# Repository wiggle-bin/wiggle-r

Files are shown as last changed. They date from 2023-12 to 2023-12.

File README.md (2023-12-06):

# WiggleR

The mission of **WiggleBin** is to craft an **open-source, intelligent [vermicomposting](https://en.wikipedia.org/wiki/Vermicompost) bin** that cultivates joy for both earthworms and their human stewards. 

In order to craft an open-source, intelligent composting bin, we want to understand the [Umwelt](https://en.wikipedia.org/wiki/Umwelt) (perceptual world) of worms. Hence, we've introduced the [WiggleR](./BUILD.md), our innovative open-source desktop composting research unit.

Join us in this thrilling endeavor! Embark on a captivating, modern-day Darwinian journey into the realm of worms by creating your very own [WiggleR](./BUILD.md).

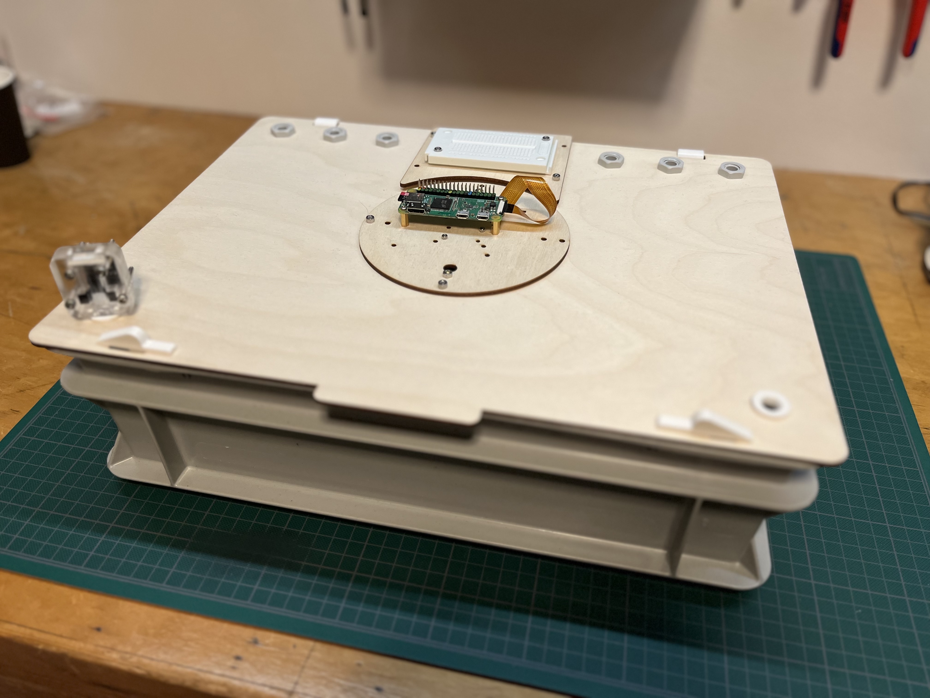
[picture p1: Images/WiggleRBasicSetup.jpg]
WiggleR - innovative open-source desktop composting research unit


## Why?

Delving into the essence of worm happiness raises intriguing queries: What defines a worm's contentment? How can we gauge their emotional state? Moreover, how do these fascinating creatures navigate and perceive their surroundings through their unique sensory mechanisms?

Unraveling these enigmas not only enhances our understanding of these small but vital ecosystem contributors but also deepens our appreciation for the interconnectedness of life on a microcosmic level.

## License

The WiggleBin is open source hardware. Hardware is covered under CERN-OHL-S-2.0 (`LICENSE.CERN-OHL-S-2.0.txt`) license and software under GPL-3.0-or-later (`LICENSE.GPL-3.0-or-later.txt`) license.

## Status

This project is in the research and testing phase. Currently our research involves trying out different sensors. See [issues](https://github.com/studiorabota/wiggle-bin/issues) for more info and how to contribute. Check [milestones](https://github.com/studiorabota/wiggle-bin/milestones) for our future plans.

## Thanks!

Many thanks to [Open Hardware Academy](https://www.openhardware.academy/01_Welcome.html) and [Stadslab Rotterdam](https://stadslabrotterdam.nl/) for making this project possible.

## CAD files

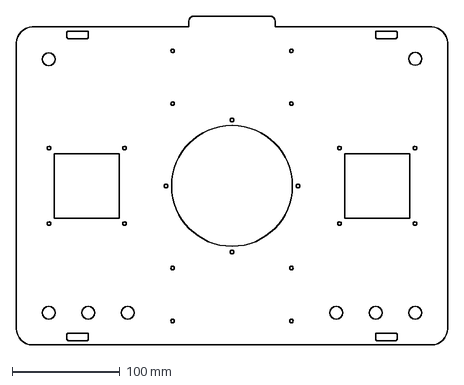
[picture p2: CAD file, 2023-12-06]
Design/BinTop/MainPlate.dxf
400.0 x 305.0 mm

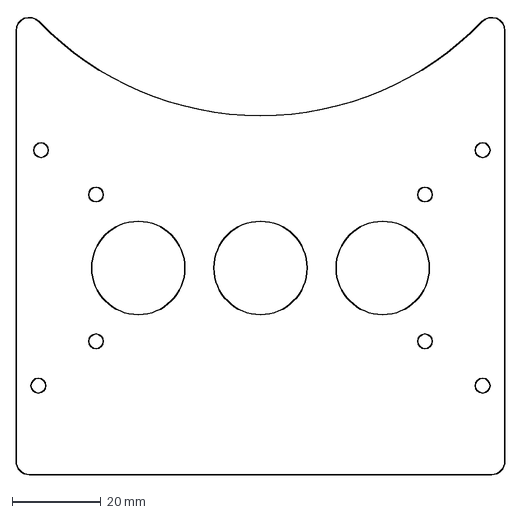
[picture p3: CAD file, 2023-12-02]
Design/BinTop/BreadboardUnit/BreadBoardPlate.dxf
110.0 x 103.1 mm

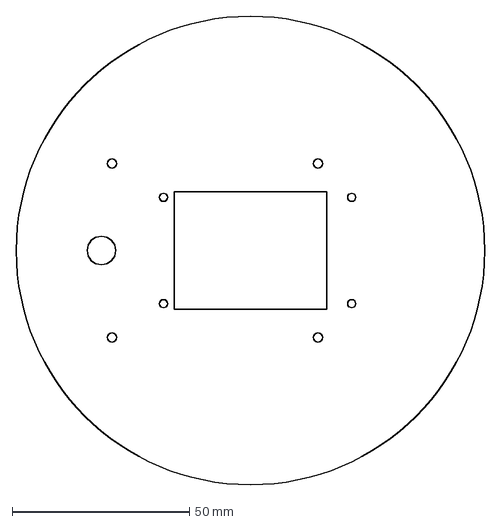
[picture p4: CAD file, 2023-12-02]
Design/BinTop/CenterUnit/DisplayBracket.dxf
132.0 x 132.0 mm

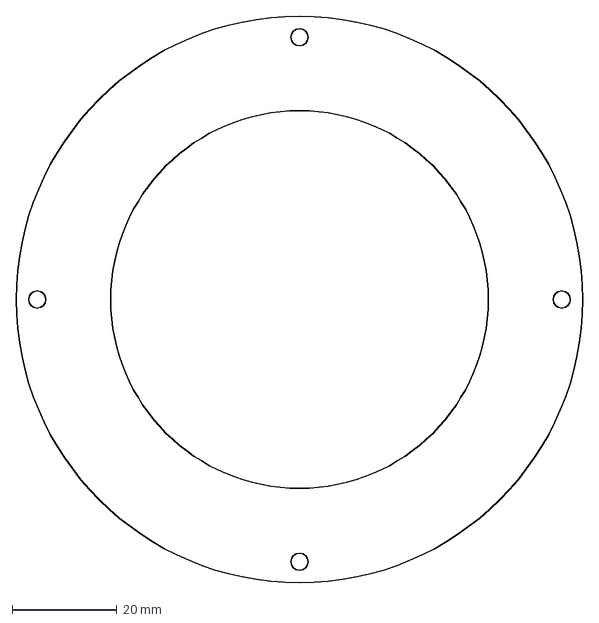
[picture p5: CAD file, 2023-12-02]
Design/BinTop/LightUnit/LightDiffuser.dxf
108.0 x 108.0 mm

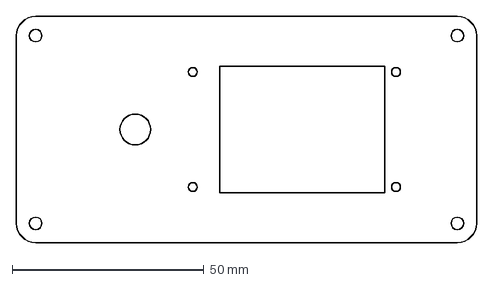
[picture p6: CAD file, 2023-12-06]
Design/BinTop/TopAttachments/ScreenPlateLaserCut.dxf
120.0 x 59.0 mm

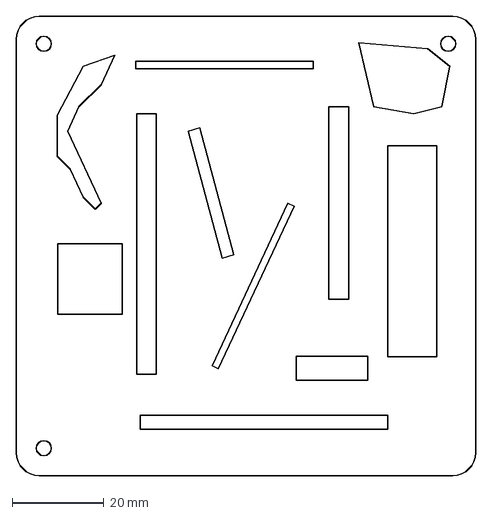
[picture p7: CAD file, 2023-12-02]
Design/TestKit/TestPlateLines.dxf
100.0 x 100.0 mm

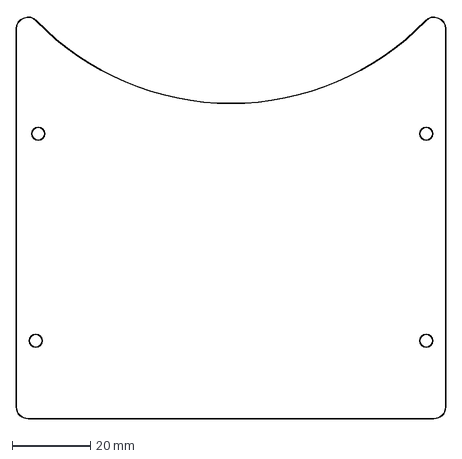
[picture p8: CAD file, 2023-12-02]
Design/BinTop/BreadboardUnit/BreadBoardTopPlate.dxf
110.0 x 103.1 mm

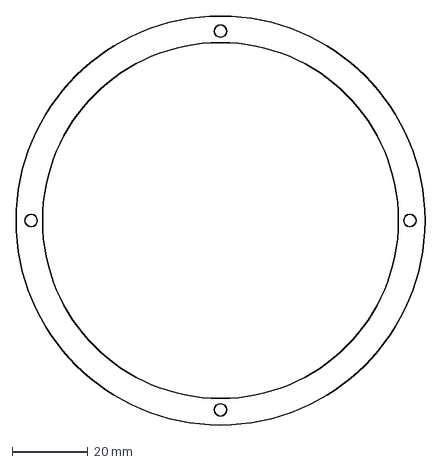
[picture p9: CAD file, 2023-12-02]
Design/BinTop/LightUnit/LightSpacer.dxf
108.0 x 108.0 mm

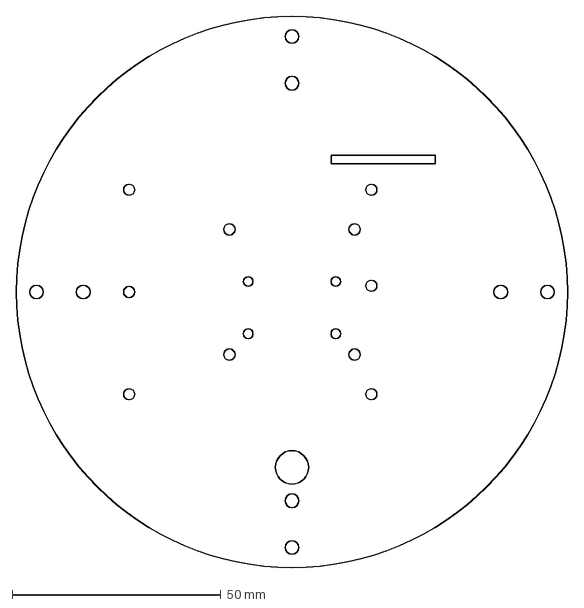
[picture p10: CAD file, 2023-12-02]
Design/BinTop/RaspberryBracket.dxf
132.0 x 132.0 mm

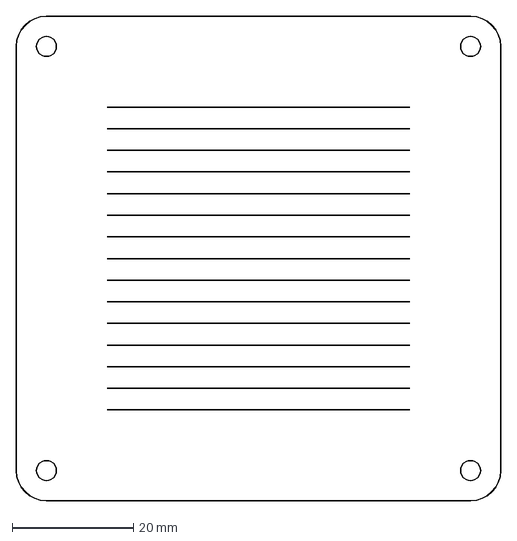
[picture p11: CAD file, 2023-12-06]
Design/BinTop/TopAttachments/AirPlate2X.dxf
80.0 x 80.0 mm

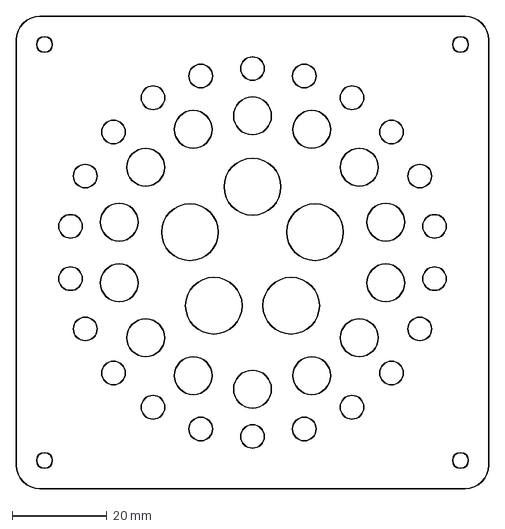
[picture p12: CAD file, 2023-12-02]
Design/TestKit/TestPlateCircles.dxf
100.0 x 100.0 mm

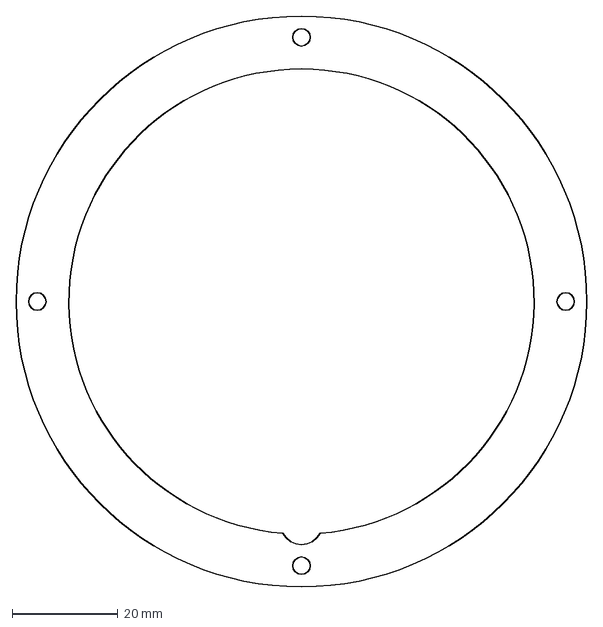
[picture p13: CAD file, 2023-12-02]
Design/BinTop/LightUnit/LightBack.dxf
108.0 x 108.0 mm

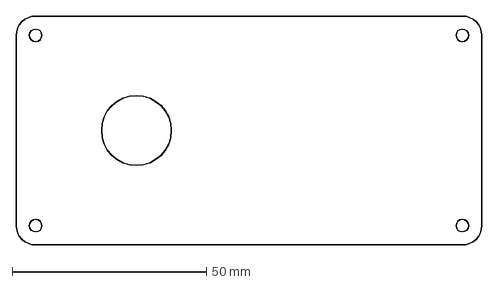
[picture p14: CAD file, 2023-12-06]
Design/BinTop/TopAttachments/ScreenPlateTopLaserCut.dxf
120.0 x 59.0 mm

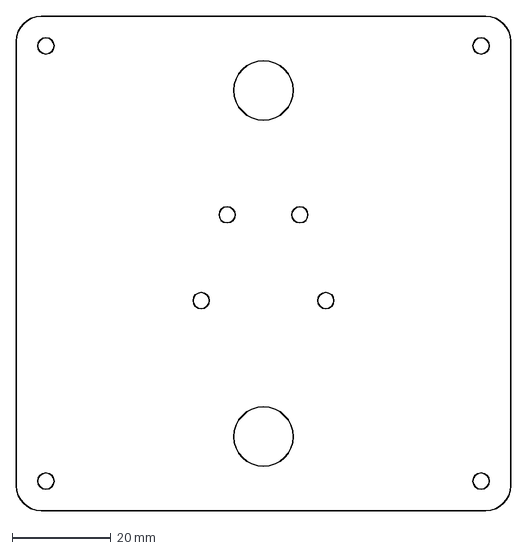
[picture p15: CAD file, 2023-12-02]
Design/TestKit/TestPlateWormGate.dxf
100.0 x 100.0 mm

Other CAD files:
Design/BinTop/TopAttachments/BreadBoardPlateLaserCut.dxf
Design/BinTop/TopAttachments/BreadBoardTopPlateLaserCut.dxf
Design/BinTop/TopAttachments/RaspberryTopPlate.dxf

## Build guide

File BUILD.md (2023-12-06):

# WiggleR - Build

The following are steps to build WiggleR V0.1.0. WiggleR is a desktop research unit for making controlled experiments with worms.

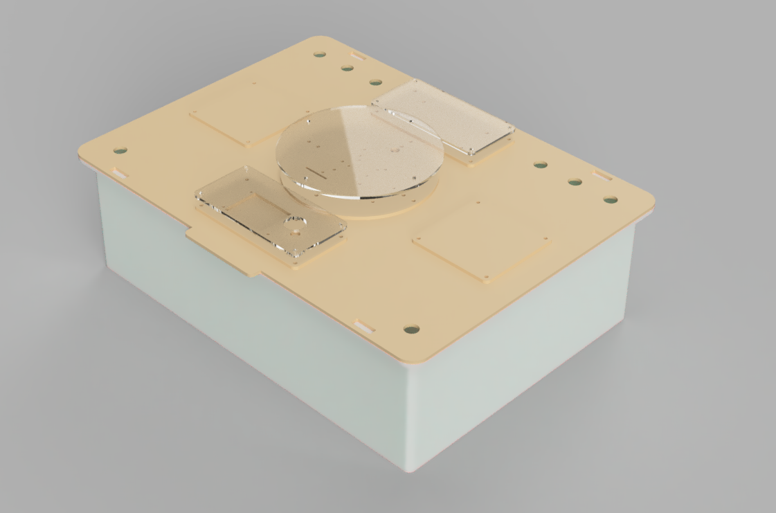
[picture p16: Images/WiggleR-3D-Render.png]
WiggleR - 3D render of the WiggleR unit


## Bill of materials for box  

### Materials
- [EuroBin 400*300](https://www.engelslogistiek.nl/webshop/stapelbare-opslag-en-transportbakken/e-line-euronorm-stapelbakken/EN-4312-1-1.html)
- Wood or acrylic
- Oil
- [M2.5 spacer kit](https://www.tinytronics.nl/shop/en/tools-and-mounting/installation-and-mounting-material/spacers/m2.5-spacer-kit)
- [M3 spacer kit](https://www.tinytronics.nl/shop/en/tools-and-mounting/installation-and-mounting-material/spacers/m3-spacer-kit)
- [Nuts and bolts](https://www.tinytronics.nl/shop/en/tools-and-mounting/installation-and-mounting-material/bolts/bolt-nut-and-washer-set-m2-m3-m4-including-3-allen-keys-1080-pieces)
- [Cable glands](https://www.tinytronics.nl/shop/en/tools-and-mounting/installation-and-mounting-material/cable-glands/cable-gland-m12-3mm-6.5mm)

### Tools
- Laser cutter
- 3D printer (optional)

### Build

Vector file for lasercutting can be found in the [`Design`](./Design/) folder.

WiggleR comprises a EuroBin for housing soil and worms, topped with a wooden lid to accommodate electronics like the Raspberry Pi.

For increased longevity, you can oil the birch wood with substances such as boiled linseed oil or Danish oil. Apply the oil using a (paper) cloth, ensuring to observe safety instructions, as oils can pose a fire hazard.

## Electronics

### Must have electronics

- Raspberry Pi or [Raspberry Zero](https://www.kiwi-electronics.com/nl/raspberry-pi-zero-wh-header-voorgesoldeerd-3328)
- [Raspberry HQ Camera](https://www.kiwi-electronics.com/nl/raspberry-pi-hq-camera-m12-mount-11243)
- [Raspberry Zero Adapters](https://www.kiwi-electronics.com/nl/raspberry-pi-zero-adapter-pack-2844)
- [Raspberry Zero Camera Adapter](https://www.kiwi-electronics.com/nl/raspberry-pi-zero-camera-adapter-2842)
- [Lens](https://www.kiwi-electronics.com/nl/m12-high-resolution-lens-12mp-113-fov-2-7mm-focal-length-11266)
- [Led Ring](https://www.tinytronics.nl/shop/nl/verlichting/ringen-en-modules/sk6812-digitale-5050-rgb-led-ring-24-leds-wit)

### Optional electronics

- [ADS1115](https://www.tinytronics.nl/shop/nl/sensoren/stroom-spanning/ads1115-16-bit-adc-i2c-module-4-kanaals)
- [Capacitive Soil Moisture sensor](https://www.tinytronics.nl/shop/en/sensors/liquid/capacitive-soil-moisture-sensor-module-with-cable). Make sure to buy a [good one](https://www.youtube.com/watch?v=IGP38bz-K48).
- [1MΩ resistor](https://www.tinytronics.nl/shop/en/components/resistors/resistors/1m%CF%89-resistor)
- [DS18B20 TO-92 Thermometer](https://www.tinytronics.nl/shop/en/sensors/temperature/ds18b20-to-92-thermometer-temperature-sensor-with-cable-waterproof-high-temperature-1m) (soil temperature)
- [DS18B20 Adapter](https://www.tinytronics.nl/shop/en/sensors/temperature/ds18b20-adapter) or 4.7kΩ resistor
- [BME680](https://www.tinytronics.nl/shop/nl/sensoren/lucht/druk/bme680-sensor-module-met-level-converter-luchtdruk-luchtkwaliteit-luchtvochtigheid-temperatuur)

### Tools
- Screw driver

### Connections

#### BME680

[Installation instuctions](https://raspberry-valley.azurewebsites.net/BME680-Sensor/)

| [RP Zero]((https://pinout.xyz/pinout/io_pi_zero)) | Sensor
--- | --- | 
| Pin 2 - 5v Power | VCC
| Pin 6 - Ground | GND
| Pin 3 - GPIO 2 | SDA
| Pin 5 - GPIO 3 | SCL

#### DS18B20

[Installation instuctions](https://www.circuitbasics.com/raspberry-pi-ds18b20-temperature-sensor-tutorial/)

| [RP Zero]((https://pinout.xyz/pinout/io_pi_zero)) | Sensor
--- | --- | 
| Pin 2 - 5v Power | VCC
| Pin 6 - Ground | GND
| Pin 7 - GPIO 4 | DAT

#### Soil Moisture Sensor

| [RP Zero]((https://pinout.xyz/pinout/io_pi_zero)) | ADS1115
--- | --- | 
| Pin 2 - 5v Power | VCC
| Pin 6 - Ground | GND
| Pin 3 - GPIO 2 | SDA
| Pin 5 - GPIO 3 | SCL

| Soil Moisture sensor | ADS1115
--- | --- | 
| AOUT | A0

[Installation instuctions](https://learn.adafruit.com/adafruit-4-channel-adc-breakouts/python-circuitpython)

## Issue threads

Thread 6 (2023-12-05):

Create a Pi-Hat PCB

studiorabota, 2023-12-05:
Should hold:

1. The screen
2. Rotary
3. Connections to all relevant sensors
4. - WormGate
5.  - accelerometer?
6.  - temp
7. - moist
8. - BME

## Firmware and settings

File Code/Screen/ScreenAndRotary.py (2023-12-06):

#!/usr/bin/python
# -*- coding: UTF-8 -*-
#import chardet
import os
import sys 
import time
import logging
import spidev as SPI
sys.path.append("..")
from lib import LCD_2inch
from PIL import Image,ImageDraw,ImageFont
from RPi import GPIO

# Rotary encoder
clk = 17
dt = 23

GPIO.setmode(GPIO.BCM)
GPIO.setup(clk, GPIO.IN, pull_up_down=GPIO.PUD_DOWN)
GPIO.setup(dt, GPIO.IN, pull_up_down=GPIO.PUD_DOWN)

counter = 30
clkLastState = GPIO.input(clk)

# Raspberry Pi pin configuration:
RST = 27
DC = 25
BL = 18
bus = 0
device = 0
logging.basicConfig(level=logging.DEBUG)
try:
    # display with hardware SPI:
    ''' Warning!!!Don't  creation of multiple displayer objects!!! '''
    # disp = LCD_2inch.LCD_2inch(spi=SPI.SpiDev(bus, device),spi_freq=10000000,rst=RST,dc=DC,bl=BL)
    disp = LCD_2inch.LCD_2inch()
    # Initialize library.
    disp.Init()
    # Clear display.
    disp.clear()

    while True:
        clkState = GPIO.input(clk)
        dtState = GPIO.input(dt)
        if clkState != clkLastState:
            if dtState != clkState:
                counter += 1
                if counter > 58:
                    counter = 0
            else:
                counter -= 1
                if counter < 11:
                    counter = 30

            print(counter)

            image = Image.open(
                f'/home/[user_name]/WiggleR/Pictures/small/2023-10-20-13-{counter}.jpg')
            image = image.rotate(180)
            disp.ShowImage(image)
        clkLastState = clkState
        time.sleep(0.01)
except IOError as e:
    logging.info(e)
except KeyboardInterrupt:
    disp.module_exit()
    logging.info("quit:")
    exit()
finally:
    GPIO.cleanup()
    disp.module_exit()

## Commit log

2023-12-02 Moved files from wiggle-bin repo to this repo
    [BottomPlate.dxf, BreadBoardPlate.dxf, BreadBoardTopPlate.dxf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]
2023-12-06 Added documentation for the new WiggleR unit
    [BottomPlate.dxf, BreadBoardPlate.dxf, BreadBoardTopPlate.dxf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]
2023-12-06 Updated lasercut files
    [AirPlate2X.dxf, BreadBoardPlateLaserCut.dxf, BreadBoardTopPlateLaserCut.dxf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]
2023-12-06 Added updated main plate
    [MainPlate.dxf]
